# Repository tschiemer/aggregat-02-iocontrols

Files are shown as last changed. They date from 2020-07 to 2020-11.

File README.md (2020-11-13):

# aggregat 02 IOControls PCB

User interface peripheral board.

For project info see: https://gitlab.zhdk.ch/aggregat-02/a01-firmware

https://gitlab.zhdk.ch/aggregat-02/a01-pcb-iocontrols

## License

This work is licensed under a Creative Commons Attribution 4.0 International License (CC BY 4.0)

## Revisions

### v1.2

- Replaced small footprint molex connectors with regular 1.00" pin headers.

### v1.1

- fixed not connected 3V3 between DIP switches
- fixed not connected button to GPIO line
- **BREAKING CHANGE** corrected CN3 connector pin assignment to fit with NUCLEO out connector (also see schematics)

## Bill of Materials

Number | Item | Cost per (10/100) Unit(s)  | Cost
--- | --- | --- | ---
1 | PCB Prototype (https://www.pcbway.com/) | 25.00* (10) | 2.50
1 | [DIP Switch SPST 8 Through Hole](https://www.digikey.ch/product-detail/en/78B08ST/GH7192-ND/726250) | 1.26 | 1.26
2 | [DIP Switch SPST 4 Through Hole](https://www.digikey.ch/product-detail/en/78B04T/GH7185-ND/726243) | 1.06 | 2.12
1 | 1 Pin header | |
1 | 2 Pin header 1.00" |  |
2 | 15 Pin header 1.00" |  |
8 | [SMD Res 270Ohm 1% 1/8W 0805 (2012 Metric)](https://www.digikey.ch/product-detail/en/CR0805-FX-2700ELF/118-CR0805-FX-2700ELFCT-ND/10673809) | 2.67 (100) | < 1.00
19 | [SMD Res 330Ohm 1% 1/8W 0805 (2012 Metric)](https://www.digikey.ch/product-detail/en/CRG0805F330R/A106061CT-ND/3477707) | 1.82 (100) | < 1.00
8 | [SMD Res 47kOhm 1% 1/8W 0805 (2012 Metric)](https://www.digikey.ch/product-detail/en/RC0805FR-0747KL/311-47.0KCRCT-ND/730920) |  1.49 (100) | < 1.00
27 | [SMD Res 100kOhm 1% 1/8W 0805 (2012 Metric)](https://www.digikey.ch/product-detail/en/RC0805FR-07100KL/311-100KCRCT-ND/730491) |  1.49 (100) | < 1.00
19| [SMD Cap 0.1uF 10% 6.3V 0805 (2012 Metric)](https://www.digikey.ch/product-detail/en/C0805C104K9RACTU/399-9155-6-ND/3523226) | 7.65 (100) | < 1.00
8 | [Bipolar (BJT) Transistor NPN 40V 800mA SOT-23-3](https://www.digikey.ch/product-detail/en/BSR14/BSR14CT-ND/965560) | 7.37 (100) | < 1.00
4 | Tactile switches |
8 | LEDs ~2 20mA | | ~2.00

* Delivery (~25.00) not included

Total material cost ~< 20.-

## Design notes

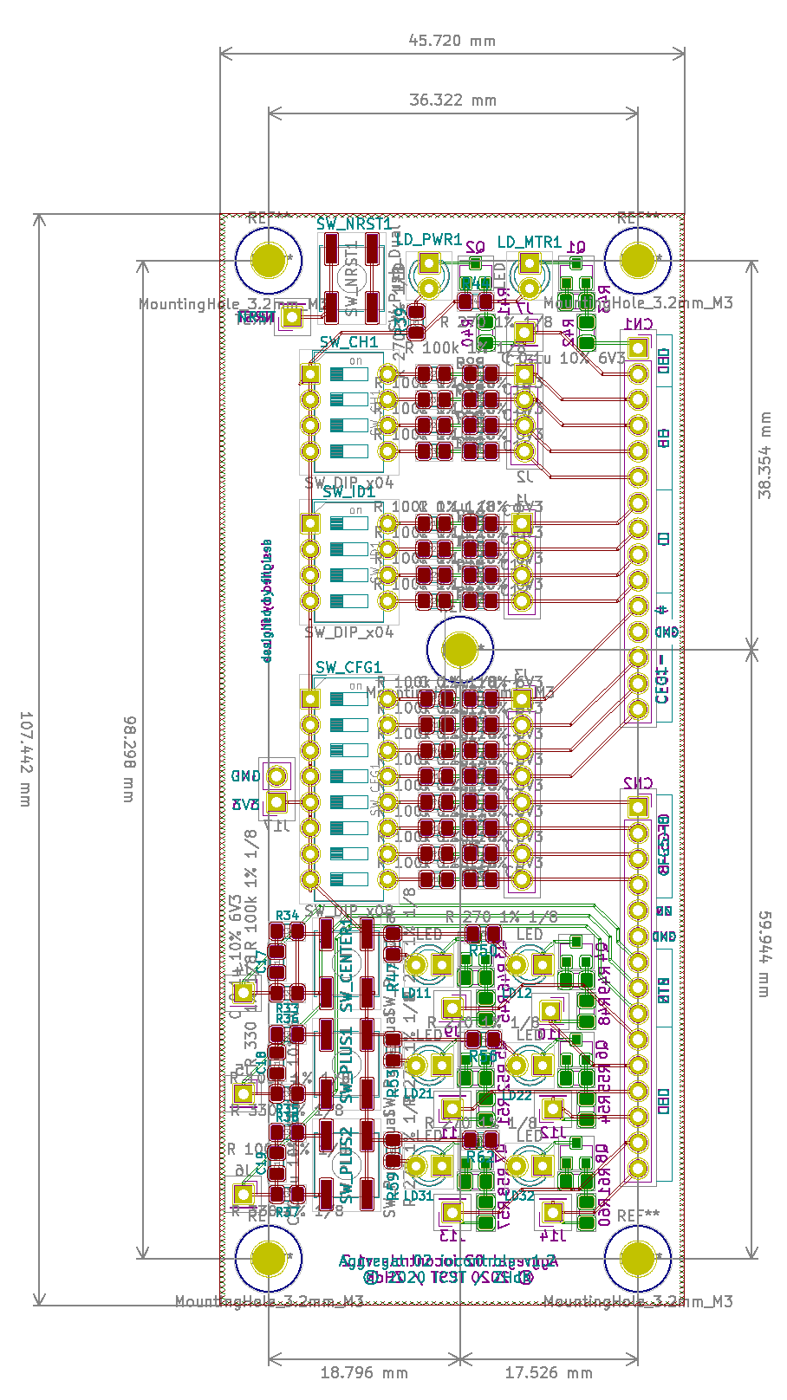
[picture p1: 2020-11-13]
pcb.png

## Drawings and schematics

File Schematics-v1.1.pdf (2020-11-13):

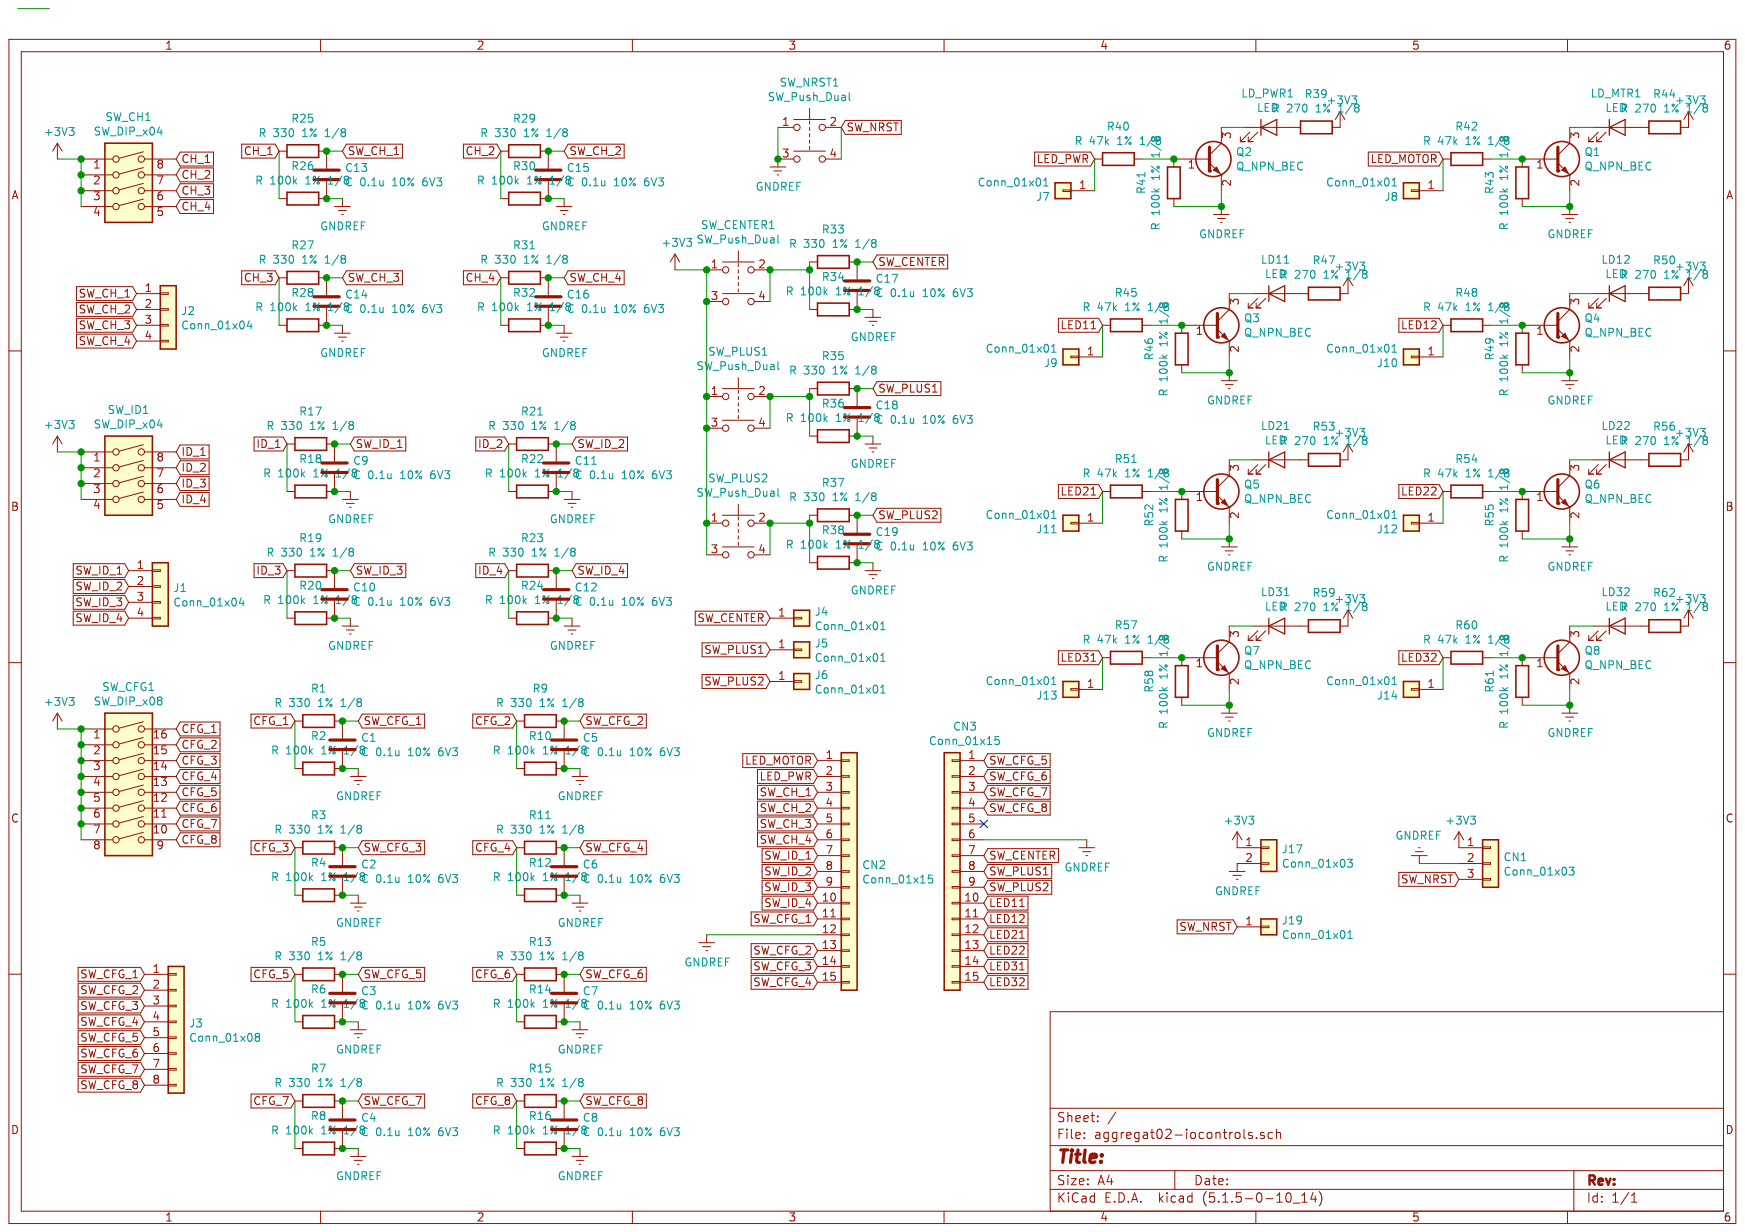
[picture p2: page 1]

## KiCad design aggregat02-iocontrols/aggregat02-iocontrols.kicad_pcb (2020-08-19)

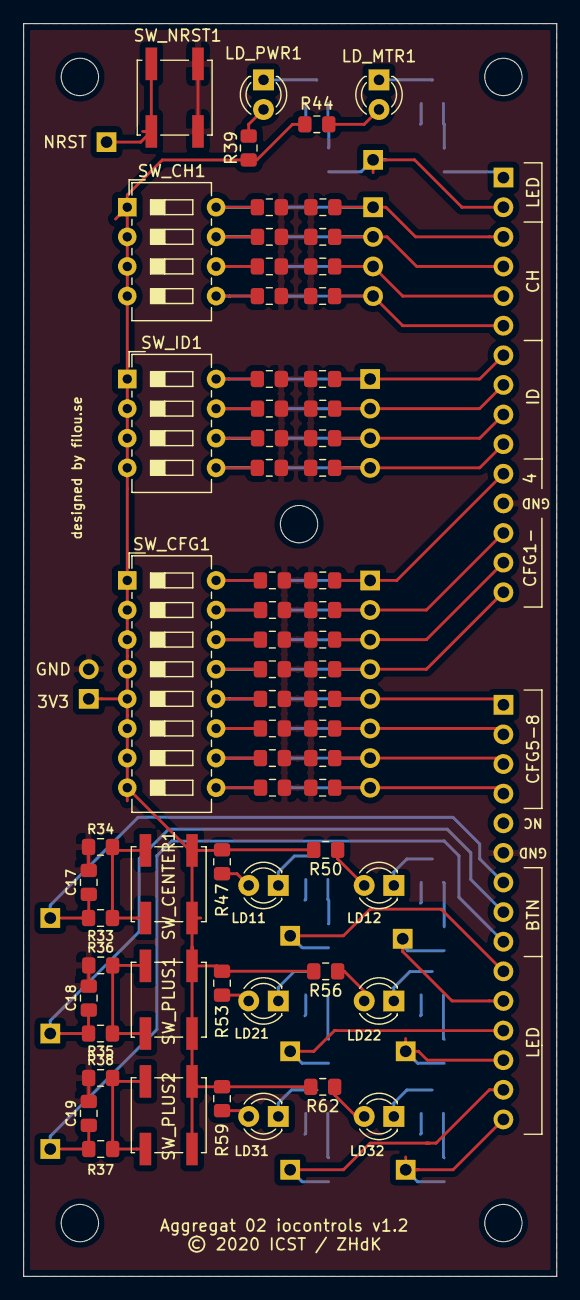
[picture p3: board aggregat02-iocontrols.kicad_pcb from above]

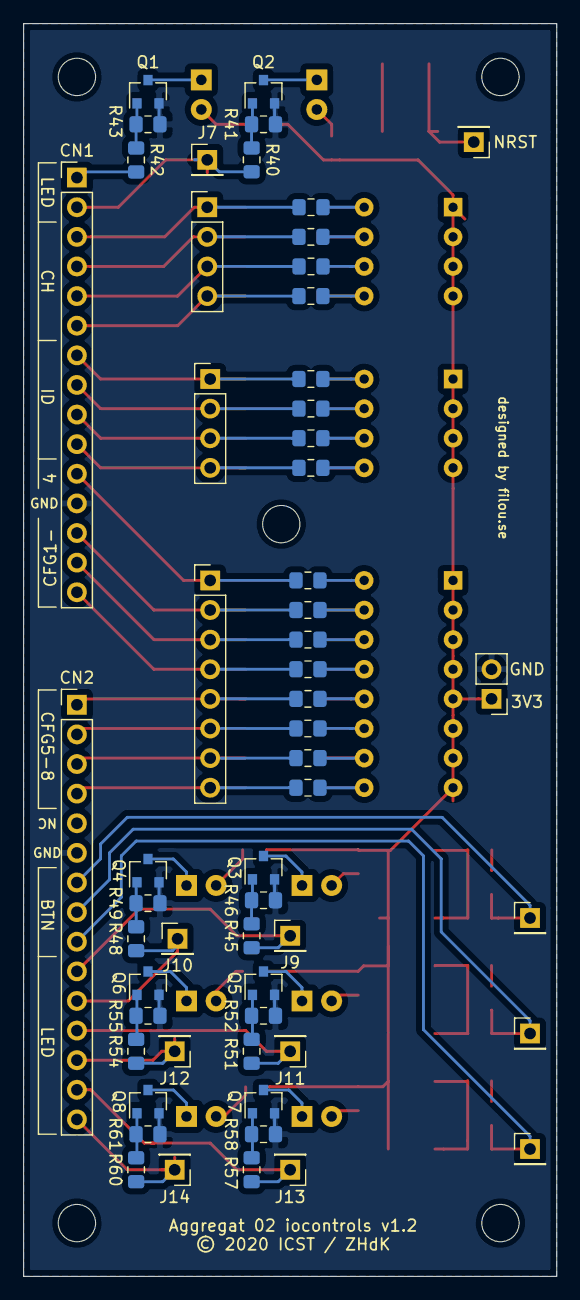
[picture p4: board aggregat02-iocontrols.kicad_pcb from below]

Board: 2 copper layers, 45.7 x 107.4 mm, 121 parts (57 on the bottom side), 73 nets.

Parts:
C1, C2, C3, C4, C5, C6, C7, C8, C9, C10, C11, C12, C13, C14, C15, C16, C17, C18, C19: C 0.1u 10% 6V3; C_0805_2012Metric_Pad1.15x1.40mm_HandSolder
CN1, CN2: Conn_01x15; PinHeader_1x15_P2.54mm_Vertical
J1, J2: Conn_01x04; PinHeader_1x04_P2.54mm_Vertical
J3: Conn_01x08; PinHeader_1x08_P2.54mm_Vertical
J4, J5, J6, J7, J9, J10, J11, J12, J13, J14: Conn_01x01; PinHeader_1x01_P2.54mm_Vertical
J17: Conn_01x03; PinHeader_1x02_P2.54mm_Vertical
LD11, LD12, LD21, LD22, LD31, LD32: LED; LED_D3.0mm
LD_MTR1: LED; LED_D3.0mm
LD_PWR1: LED; LED_D3.0mm
NRST: Conn_01x01; PinHeader_1x01_P2.54mm_Vertical
Q1, Q2, Q3, Q4, Q5, Q6, Q7, Q8: Q_NPN_BEC; SOT-23
R1, R3, R5, R7, R9, R11, R13, R15, R17, R19, R21, R23, R25, R27, R29, R31, R33, R35, R37: R 330 1% 1/8; R_0805_2012Metric_Pad1.15x1.40mm_HandSolder
R2, R4, R6, R8, R10, R12, R14, R16, R18, R20, R22, R24, R26, R28, R30, R32, R34, R36, R38, R41, R43, R46, R49, R52, R55, R58, R61: R 100k 1% 1/8; R_0805_2012Metric_Pad1.15x1.40mm_HandSolder
R39, R44, R47, R50, R53, R56, R59, R62: R 270 1% 1/8; R_0805_2012Metric_Pad1.15x1.40mm_HandSolder
R40, R42, R45, R48, R51, R54, R57, R60: R 47k 1% 1/8; R_0805_2012Metric_Pad1.15x1.40mm_HandSolder
SW_CENTER1: SW_Push_Dual; SW_Push_1P1T_NO_CK_KSC6xxJ
SW_CFG1: SW_DIP_x08; SW_DIP_SPSTx08_Slide_6.7x21.88mm_W7.62mm_P2.54mm_LowProfile
SW_CH1: SW_DIP_x04; SW_DIP_SPSTx04_Slide_6.7x11.72mm_W7.62mm_P2.54mm_LowProfile
SW_ID1: SW_DIP_x04; SW_DIP_SPSTx04_Slide_6.7x11.72mm_W7.62mm_P2.54mm_LowProfile
SW_NRST1: SW_Push_Dual; SW_Push_1P1T_NO_CK_KSC6xxJ
SW_PLUS1, SW_PLUS2: SW_Push_Dual; SW_Push_1P1T_NO_CK_KSC6xxJ

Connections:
+3V3: J17.1, R39.2, R44.2, R47.2, R50.2, R53.2, R56.2, R59.2, R62.2, SW_CENTER1.1, SW_CFG1.1, SW_CFG1.2, SW_CFG1.3, SW_CFG1.4, SW_CFG1.5, SW_CFG1.6, SW_CFG1.7, SW_CFG1.8, SW_CH1.1, SW_CH1.2, SW_CH1.3, SW_CH1.4, SW_ID1.1, SW_ID1.2, SW_ID1.3, SW_ID1.4, SW_PLUS1.1, SW_PLUS2.1
CFG_1: R1.2, R2.2, SW_CFG1.16
CFG_2: R9.2, R10.2, SW_CFG1.15
CFG_3: R3.2, R4.2, SW_CFG1.14
CFG_4: R11.2, R12.2, SW_CFG1.13
CFG_5: R5.2, R6.2, SW_CFG1.12
CFG_6: R13.2, R14.2, SW_CFG1.11
CFG_7: R7.2, R8.2, SW_CFG1.10
CFG_8: R15.2, R16.2, SW_CFG1.9
CH_1: R25.2, R26.2, SW_CH1.8
CH_2: R29.2, R30.2, SW_CH1.7
CH_3: R27.2, R28.2, SW_CH1.6
CH_4: R31.2, R32.2, SW_CH1.5
GNDREF: C1.2, C2.2, C3.2, C4.2, C5.2, C6.2, C7.2, C8.2, C9.2, C10.2, C11.2, C12.2, C13.2, C14.2, C15.2, C16.2, C17.2, C18.2, C19.2, CN1.12, CN2.6, J17.2, Q1.2, Q2.2, Q3.2, Q4.2, Q5.2, Q6.2, Q7.2, Q8.2, R2.1, R4.1, R6.1, R8.1, R10.1, R12.1, R14.1, R16.1, R18.1, R20.1, R22.1, R24.1, R26.1, R28.1, R30.1, R32.1, R34.1, R36.1, R38.1, R41.2, R43.2, R46.2, R49.2, R52.2, R55.2, R58.2, R61.2, SW_NRST1.1
ID_1: R17.2, R18.2, SW_ID1.8
ID_2: R21.2, R22.2, SW_ID1.7
ID_3: R19.2, R20.2, SW_ID1.6
ID_4: R23.2, R24.2, SW_ID1.5
LED11: CN2.10, J9.1, R45.2
LED12: CN2.11, J10.1, R48.2
LED21: CN2.12, J11.1, R51.2
LED22: CN2.13, J12.1, R54.2
LED31: CN2.14, J13.1, R57.2
LED32: CN2.15, J14.1, R60.2
LED_MOTOR: CN1.1, R42.2
LED_PWR: CN1.2, J7.1, R40.2
unnamed: LD11.1, Q3.3
unnamed: LD11.2, R47.1
unnamed: LD12.1, Q4.3
unnamed: LD12.2, R50.1
unnamed: LD21.1, Q5.3
unnamed: LD21.2, R53.1
unnamed: LD22.1, Q6.3
unnamed: LD22.2, R56.1
unnamed: LD31.1, Q7.3
unnamed: LD31.2, R59.1
unnamed: LD32.1, Q8.3
unnamed: LD32.2, R62.1
unnamed: LD_MTR1.1, Q1.3
unnamed: LD_MTR1.2, R44.1
unnamed: LD_PWR1.1, Q2.3
unnamed: LD_PWR1.2, R39.1
unnamed: Q1.1, R42.1, R43.1
unnamed: Q2.1, R40.1, R41.1
unnamed: Q3.1, R45.1, R46.1
unnamed: Q4.1, R48.1, R49.1
unnamed: Q5.1, R51.1, R52.1
unnamed: Q6.1, R54.1, R55.1
unnamed: Q7.1, R57.1, R58.1
unnamed: Q8.1, R60.1, R61.1
unnamed: R33.2, R34.2, SW_CENTER1.2
unnamed: R35.2, R36.2, SW_PLUS1.2
unnamed: R37.2, R38.2, SW_PLUS2.2
SW_CENTER: C17.1, CN2.7, J4.1, R33.1
SW_CFG_1: C1.1, CN1.11, J3.1, R1.1
SW_CFG_2: C5.1, CN1.13, J3.2, R9.1
SW_CFG_3: C2.1, CN1.14, J3.3, R3.1
SW_CFG_4: C6.1, CN1.15, J3.4, R11.1
SW_CFG_5: C3.1, CN2.1, J3.5, R5.1
SW_CFG_6: C7.1, CN2.2, J3.6, R13.1
SW_CFG_7: C4.1, CN2.3, J3.7, R7.1
SW_CFG_8: C8.1, CN2.4, J3.8, R15.1
SW_CH_1: C13.1, CN1.3, J2.1, R25.1
SW_CH_2: C15.1, CN1.4, J2.2, R29.1
SW_CH_3: C14.1, CN1.5, J2.3, R27.1
SW_CH_4: C16.1, CN1.6, J2.4, R31.1
SW_ID_1: C9.1, CN1.7, J1.1, R17.1
SW_ID_2: C11.1, CN1.8, J1.2, R21.1
SW_ID_3: C10.1, CN1.9, J1.3, R19.1
SW_ID_4: C12.1, CN1.10, J1.4, R23.1
SW_NRST: NRST.1, SW_NRST1.2
SW_PLUS1: C18.1, CN2.8, J5.1, R35.1
SW_PLUS2: C19.1, CN2.9, J6.1, R37.1

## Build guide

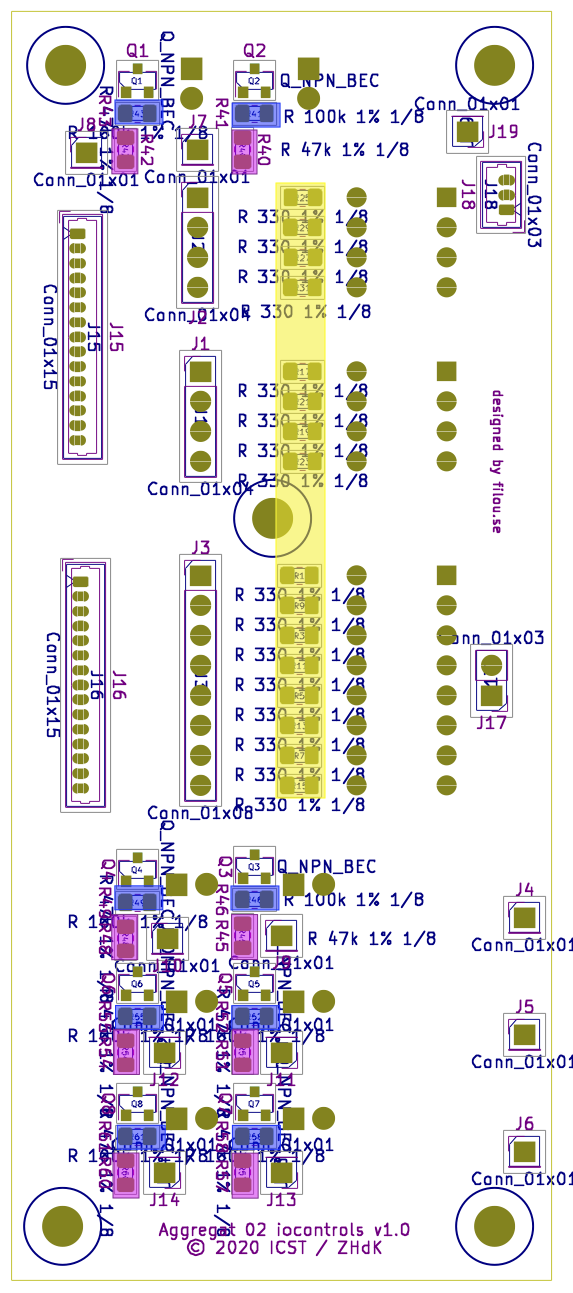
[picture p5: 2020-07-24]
assembly-back.png

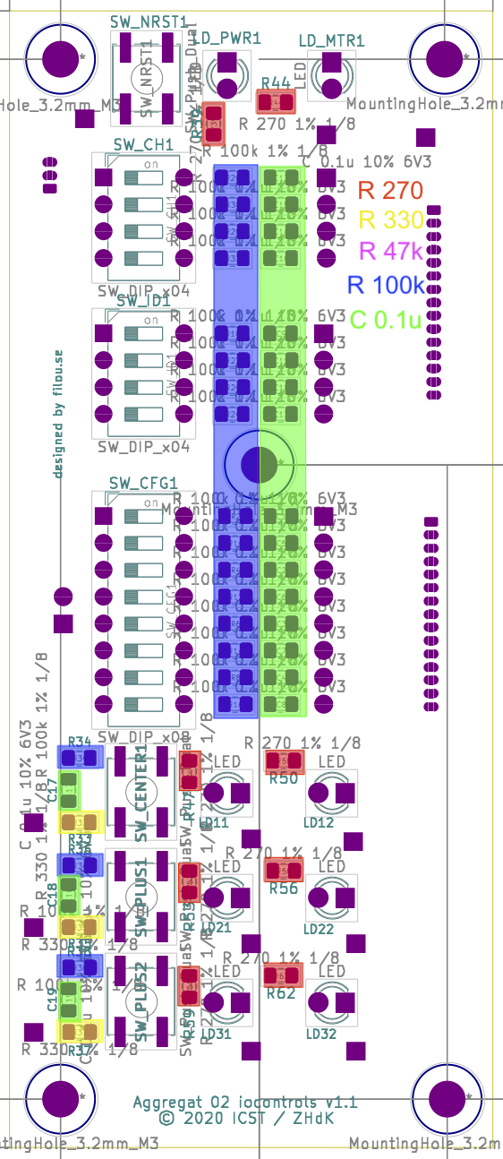
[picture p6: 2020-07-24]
assembly-front.png

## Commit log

2020-07-23 gitignore and bugfix (non-connected 3V3)
    [aggregat02-iocontrols.kicad_pcb]
2020-07-24 schematic + assembly help
2020-07-24 updated schematics
2020-07-24 assembly helpers
2020-11-13 latest gerber files

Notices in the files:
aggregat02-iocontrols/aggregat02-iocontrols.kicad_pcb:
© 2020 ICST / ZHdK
